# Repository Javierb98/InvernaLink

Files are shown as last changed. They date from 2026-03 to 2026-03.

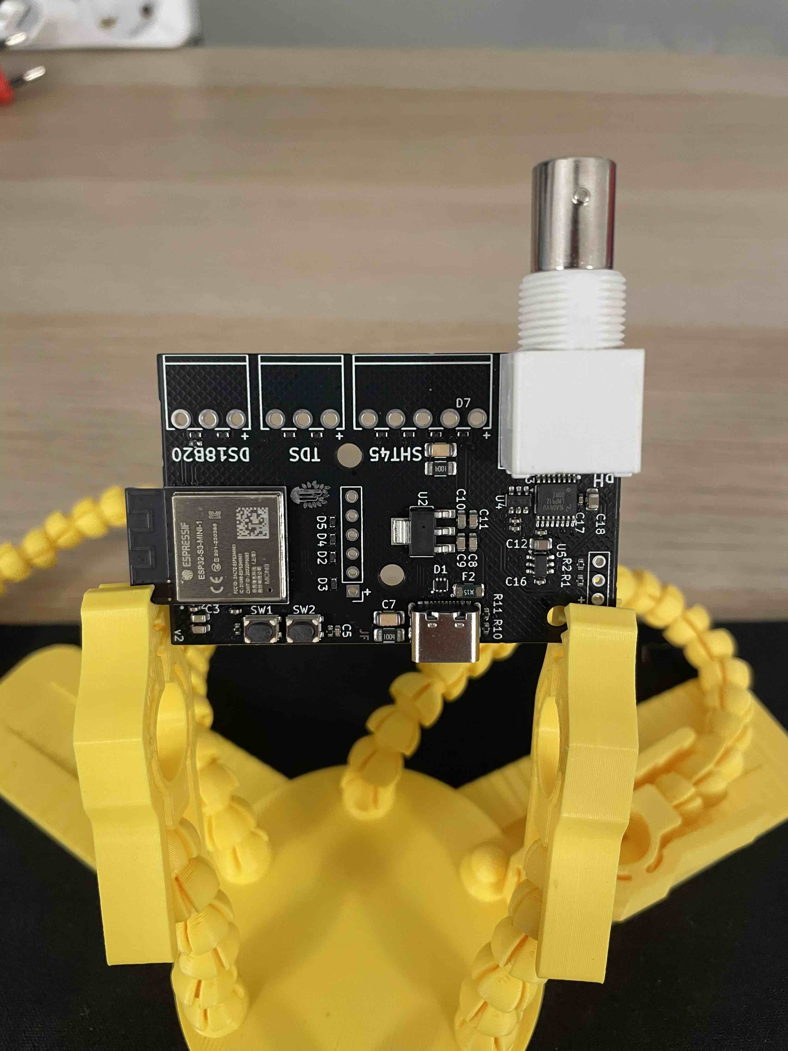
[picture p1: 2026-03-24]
Images/IMG_6064.jpg

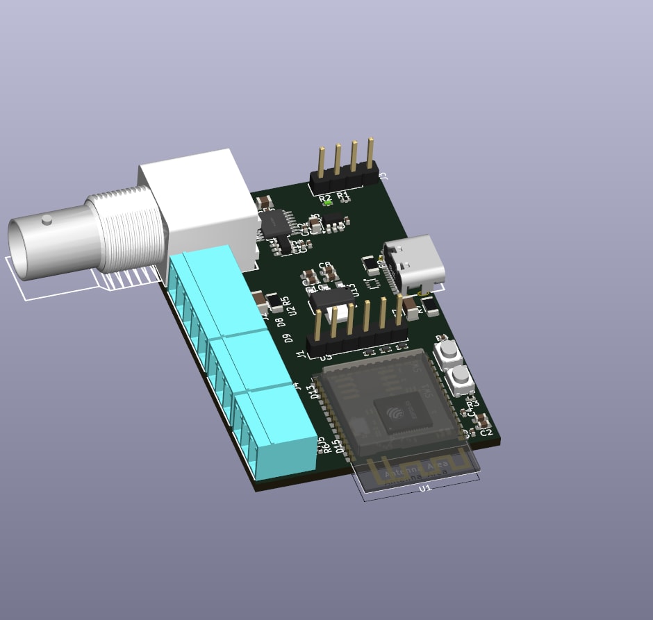
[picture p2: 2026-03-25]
Images/image.png.jpeg

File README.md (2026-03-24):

# Invernalink 🌱

**An open-source garden monitoring system powered by Home Assistant**

Invernalink is a modular, DIY-friendly system designed to help you monitor and automate your garden, greenhouse, or indoor growing environment. Built with flexibility and openness in mind, it integrates seamlessly with Home Assistant and is designed to be accessible for makers, growers, and developers alike.

---

## 🔗 Project Links

* 🌐 Project page: [https://evocultiva.org/project/invernalink-an-open-source-garden-monitoring-system-powered-by-home-assistant](https://evocultiva.org/project/invernalink-an-open-source-garden-monitoring-system-powered-by-home-assistant)
* 🛒 Support the project: (https://evocultiva.org/store/product/2)

---

## 📦 Repository Contents

This repository includes:

* **Gerber files** – Ready-to-manufacture PCB designs
* **STL files** – 3D-printable enclosures and components
* **YAML configurations** – Home Assistant integration and setup

Everything you need to build, modify, and extend Invernalink is here.

---

## 🚀 Features

* 🌡️ Environmental monitoring (temperature, humidity, CO2, Light etc.)
* 🔌 Home Assistant integration. you can 
* 🧩 Modular hardware design
* 🛠️ Fully customizable. The sensors are meant to be switched out and upgraded.

---

## 🧑‍🔧 Getting Started

1. Download or clone this repository
2. Manufacture the PCB using the provided Gerber files
3. 3D print the enclosure from the STL files
4. Assemble the hardware components
5. Import and adapt the YAML configuration into Home Assistant
6. Start monitoring your garden 🌿

> Detailed build instructions and documentation are available on the project page.

---

## 🤝 Contributing

Invernalink is an open-source project, and contributions are highly encouraged.

You can help by:

* Improving the hardware design
* Optimizing the PCB layout
* Enhancing the Home Assistant YAML configurations
* Adding new sensors or features
* Reporting bugs or suggesting improvements

Feel free to open issues, submit pull requests, or fork the project and experiment.

---

## 💡 Collaboration Invitation

This project is meant to grow with the community. Whether you're a developer, maker, or gardener, your ideas and improvements are welcome.

If you build your own version, modify the design, or extend the functionality, please share it! Let’s make Invernalink better together.

---

## ❤️ Support the Project

If you find Invernalink useful and want to support ongoing development, consider purchasing a kit or product from the store:

👉 [https://evocultiva.org/store/product/2](https://evocultiva.org/store/product/2)

Your support helps:

* Fund further development
* Improve documentation
* Expand features and compatibility
* Keep the project open and accessible

---

## 📜 License

This project is open-source. Please check the LICENSE file for details.

---

## 🌿 Final Notes

Invernalink is built on the idea that technology can empower sustainable growing. Whether you're managing a greenhouse or a small home garden, this system is here to help you understand and optimize your environment.

Happy growing! 🌱

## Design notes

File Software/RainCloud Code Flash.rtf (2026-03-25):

esphome:
name: sensor
friendly_name: InvernaLink

esp32:
board: esp32dev
framework:
type: arduino

# Define sensor pins as substitutions for easy modification

substitutions:
tds_pin: "2"
ds18b20_pin: "1"
tsl2591_int_pin: "21"

# Configure I2C for multiple sensors

i2c:
sda: GPIO15
scl: GPIO16
scan: true
id: bus_a

wifi:
ap:
ssid: “InvernaLink”
password: "12345678"

captive_portal:

api:

ota:
platform: esphome

logger:

web_server:
port: 80

# Sensors

sensor:
# TSL2591 Light Sensor

- platform: tsl2591
name: "Ambient Light"
id: light_sensor
address: 0x29
update_interval: 2s
interrupt_pin: GPIO${tsl2591_int_pin}
unit_of_measurement: "lux"

# SHT45 Temperature & Humidity Sensor

- platform: sht4x
temperature:
name: "Air Temperature"
humidity:
name: "Air Humidity"
address: 0x44
update_interval: 2s

# pH Sensor

- platform: ads1115
multiplexer: 'A0_GND'
gain: 4.096
name: "pH Level"
update_interval: 2s
unit_of_measurement: "pH"
accuracy_decimals: 1

# SCD41 CO2, Temperature & Humidity Sensor

- platform: scd4x
co2:
name: "CO2 Level"
temperature:
name: "SCD41 Temperature"
humidity:
name: "SCD41 Humidity"
address: 0x62
update_interval: 2s

# TDS Sensor

- platform: adc
pin: GPIO${tds_pin}
name: "TDS Level"
update_interval: 2s
unit_of_measurement: "ppm"
accuracy_decimals: 0

# DS18B20 Water Temperature Sensor

- platform: dallas
address: 0x28
pin: GPIO${ds18b20_pin}
name: "Water Temperature"
update_interval: 60s
unit_of_measurement: "°C"
accuracy_decimals: 1

# Dallas OneWire Bus for DS18B20

dallas:
- pin: GPIO${ds18b20_pin}

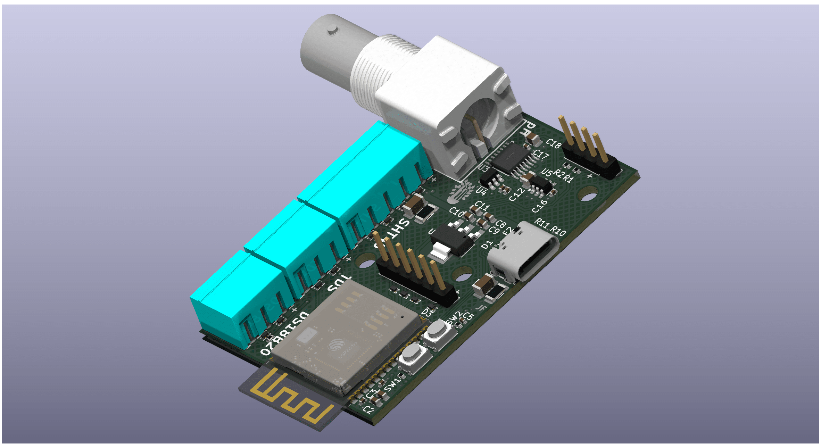
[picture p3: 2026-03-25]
Images/Side view.png

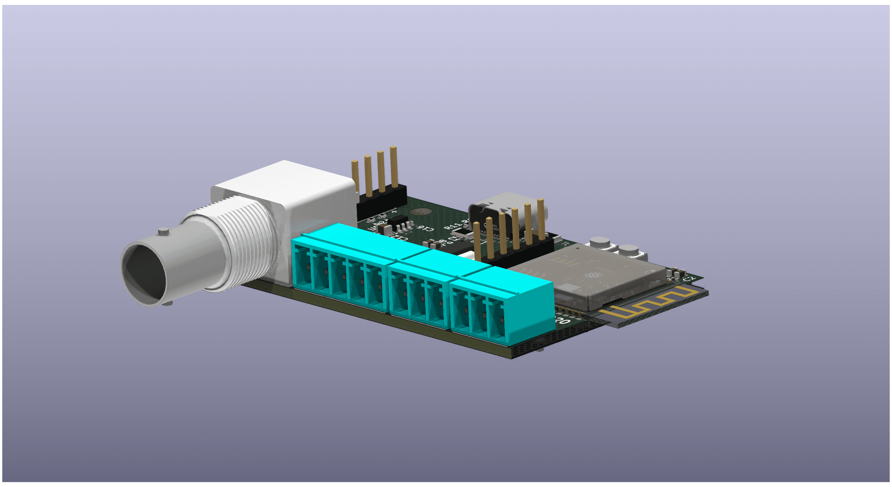
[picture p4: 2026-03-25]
Images/Front view.png

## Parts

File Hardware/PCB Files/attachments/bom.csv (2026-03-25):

Designator | Footprint | Quantity | Value | LCSC Part #
C1, C10, C11, C2, C8, C9 | 0603 | 6 | 10uF | C96446
C12, C18 | 0805 | 2 | 22uF | C45783
C13, C15, C16, C17, C3, C5 | 0402 | 6 | 100nF | C1525
C14, C4 | 0402 | 2 | 2.2uF | C12530
C6, C7 | 1206 | 2 | 4.7nF 2kV | C41017
D1 | SOT-666-6_L1.6-W1.2-P0.50-LS1.6-BL | 1 | USBLC6-2P6_C2827693 | C2827693
D12, D13, D14, D15, D2, D3, D4, D5, D6, D7, D8, D9 | DFN1006-2L-BI | 12 | JEN1006-3.3V-ULC | C2982301
F2 | 1206 | 1 | Polyfuse | C2153797
R1, R2 | 0402 | 2 | 2k | C4109
R10, R11 | 0402 | 2 | 5.1k | C25905
R3, R4 | 0402 | 2 | 10k | C25744
R5, R7 | 1206 | 2 | 1M | C17927
R6 | 0402 | 1 | 4.7k | C25900
RF1 | ANT-TH_KH-BNC75-3511 | 1 | KH-BNC75-3511 | C2837588
SW1, SW2 | SW-SMD_4P-L4.2-W3.2-P2.15-LS4.5 | 2 | GT-TC048D-H025-L1 | C843674
U13 | USB-C-SMD_GT-USB-7010I | 1 | GT-USB-7010I | C5362630
U2 | SOT-223-3_L6.5-W3.4-P2.30-LS7.0-BR-1 | 1 | HE2028A33FR | C5199431
U3 | TSSOP-16_L5.0-W4.4-P0.65-LS6.4-BL | 1 | LMP91200MTX/NOPB | C2678419
U4 | SOT-23-6 | 1 | MCP3421A0T-ECH | C29454
U5 | SOT-23-6 | 1 | REF35205QDBVR | C6966710
U6 | BULETM-SMD_ESP32-S3-MINI-1-N8 | 1 | ESP32-S3-MINI-1-N8 | C2913206

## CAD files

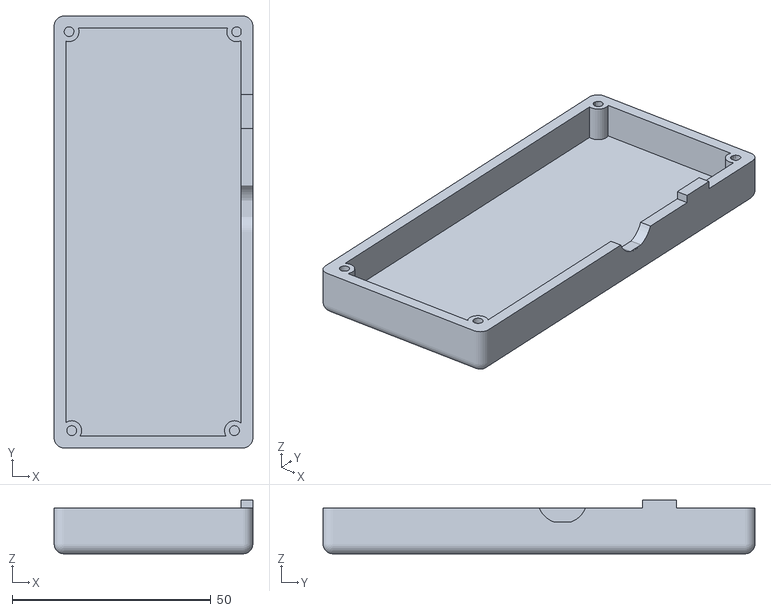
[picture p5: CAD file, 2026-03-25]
Hardware/STL case/RainCloud Box Upper.stl
50.0 x 108.7 x 13.5

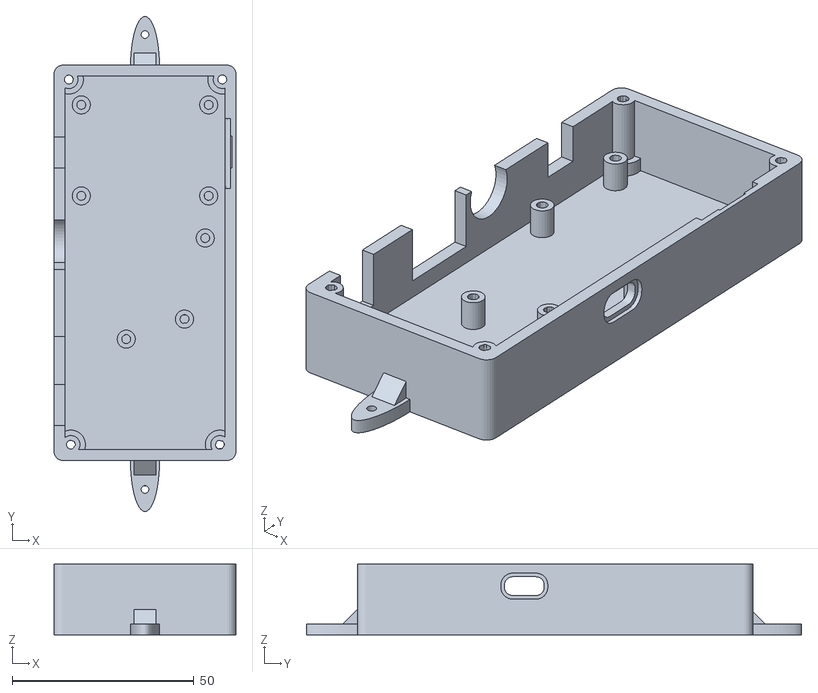
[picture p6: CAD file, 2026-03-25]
Hardware/STL case/RainCloud Box Lower.stl
50.0 x 136.0 x 19.5

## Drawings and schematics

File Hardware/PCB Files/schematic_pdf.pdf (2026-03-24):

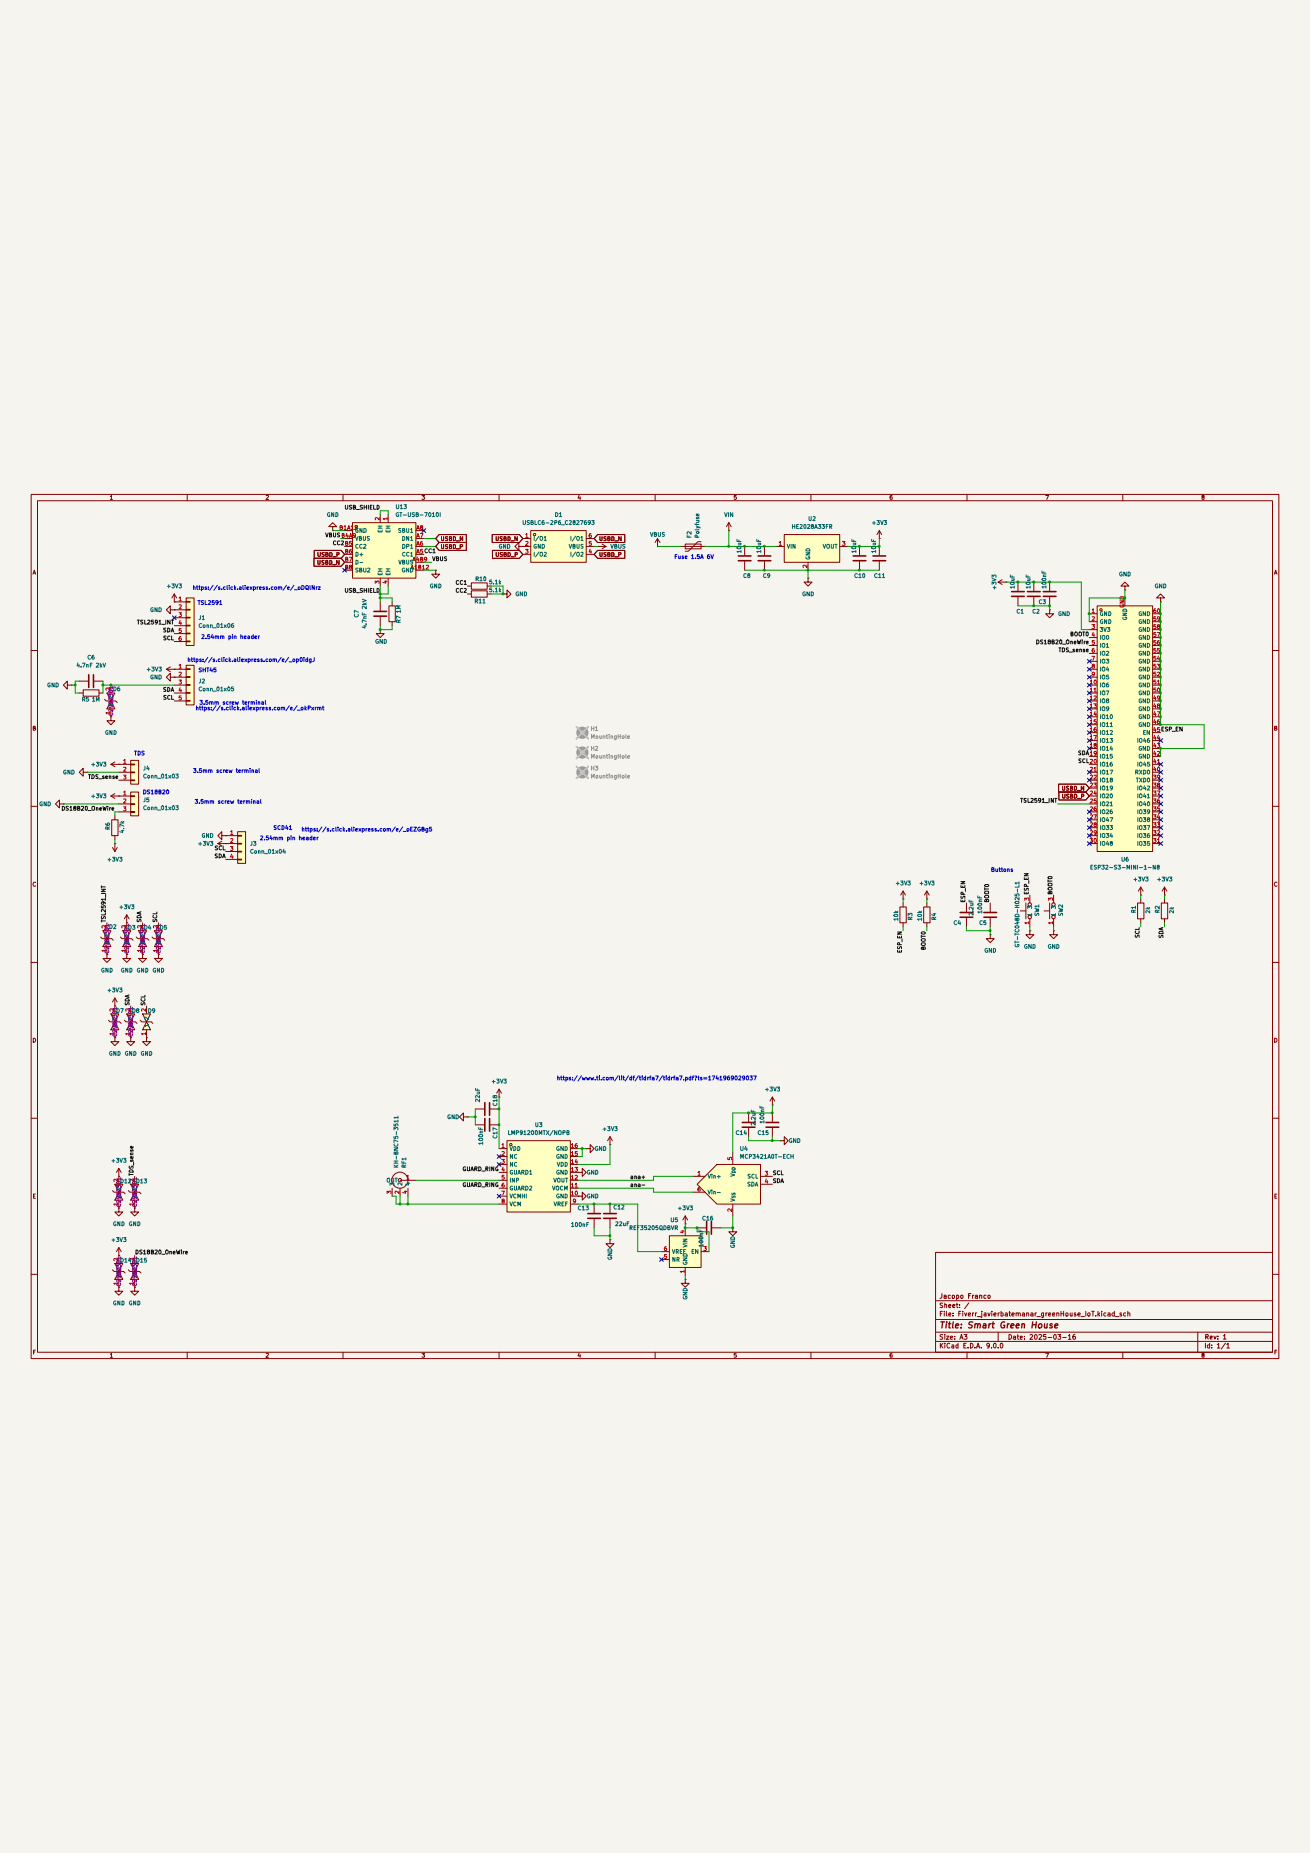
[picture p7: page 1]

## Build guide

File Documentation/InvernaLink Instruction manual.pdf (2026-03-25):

# OPERATORS MANUAL:

# INVERNALINK V1

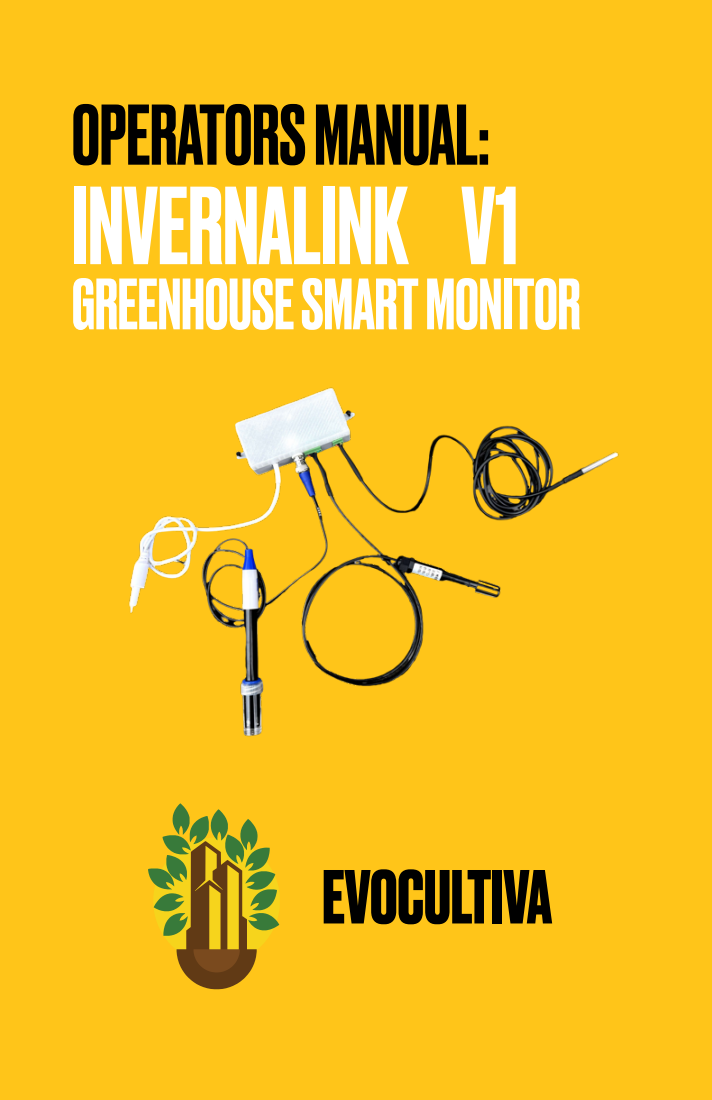
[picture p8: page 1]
EVOCULTIVA

GREENHOUSE SMART MONITOR

# TABLE OF CONTENTS

1. Components
2. Installation
3. Connecting to Wi-Fi
4. Integrating with Home Assistant
5. Connecting & Disconnecting Sensors
6. Safe Operation
7. Support & Warranty Information

© EvoCultiva
Javier Bateman Aramendia
www.Evocultiva.org

# COMPONENTS

A. USB-A to USB-C charging/data cable
B. TDS meter
C. TSL2591 (light sensor module
D. SCD40 (CO2 sensor module)
E. SHT40 (temp & humidity sensor)
F. DS18b20 (water temp module)
G. pH sensor
H. ESP32-S3-Mini

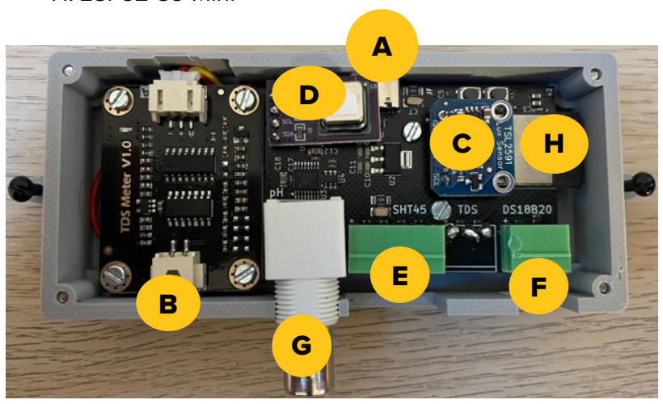
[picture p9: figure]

# INSTALLATION

To start, you need to set up an instance of Home Assistant. If you’ve purchased an InvernaLink Hub, refer to the installation manual for the InvernaLink Hub first. In the case that you’ve already got an instance of home assistant up, then we will install the InvernaLink.
1. decide where you want to install the InvernaLink, we recommend you install it close to your nutrient stock tank, in a position safe from being splashed by water. Do not cover the case in order to allow the light reading to function. Do not leave the case outside exposed to direct elements
2. When you’ve decided where you want it, make sure the case is oriented with the cables facing left and right. Use a marker and mark the two tab holes outside the case. Use these holes as the guide for whatever drilling you need to do, then simply attach the case via the pre drilled tabs
3. Once the case is setup, simply plug in the USB-C charge cable either to the InvernaLink Hub, or to an appropriate USB outlet to power it up You should be able to see a blue LED light up inside the case to indicate there is power.

# CONNECTING TO WI-FI AND HOME ASSISTANT

1. Wait 1–2 minutes after powering on.
2. Open Wi-Fi settings on your phone or computer.
3. Connect to the “InvernaLink” network.
4. In a browser (safari, crome, etc) go to 192.168.4.1
5. Input your home Wi-Fi name and password.
6. InvernaLink will then connect to your home network and shut down its temporary access point. This process might take 1-2 minutes, be patient.
7. Once the InvernaLink is connected to the wifi, go to your home assistant, and look for a new device. and add it to your dashboard as desired.
8. If for any reason the installation does not go smoothly, feel free to contact us on our website and we will help guide you through the installation process.

# CONNECTING & DISCONNECTING SENSORS

To ensure safe and reliable operation when connecting or disconnecting sensors, follow these guidelines:
Sensor Lifespan
The light, CO2, air temp/humidity, and water temp sensors should last for years to come if well taken care of.
The pH sensor is shortest lived, though it self calibrates the life of the sensor assuming it is constantly submerged will be between 6-8 months, after that its accuracy will diminish
the EC sensor should last a few years if you make sure to keep it in good condition (don’t allow bacteria and mold to build up on it in order to increase lifespan). Power Safety
Always disconnect power before connecting or removing any sensors to prevent electrical shorts or damage to internal components.
Avoid touching exposed contacts when the device is powered.
Approved Cables and Ports
Use only the supplied USB-C cable and ensure all connectors are compatible with the InvernaLink system.

For extensions or replacements, use cables and adapters rated for data and power transmission. Moisture and Corrosion Check
Inspect all sensor connectors and ports for moisture, rust, or corrosion before making any connections. If any moisture is present, dry thoroughly and clean with isopropyl alcohol if needed before plugging in. Sensor Handling
Handle sensors by the plastic housing or designated grip areas. Avoid pulling on wires.
Do not bend or stress sensor cables unnecessarily; use strain reliefs if installing in permanent locations. Connection Order
Connect sensors only after the InvernaLink unit is securely mounted and powered off.
Plug in one sensor at a time and ensure a snug, secure fit. Loose connections may result in faulty readings. Disconnecting Sensors
To disconnect, gently pull the connector, not the cable, to avoid damaging the wire or port.
Do not twist or force connectors—if resistance is felt, double-check alignment and try again.
After Reconnecting
Once reconnected and powered on, verify that all sensors are being detected correctly in your Home Assistant dashboard or monitoring software.

# SAFE OPERATION

To ensure the safe and effective operation of your InvernaLink device, please adhere strictly to the following guidelines:

Environmental Exposure
The InvernaLink is not rated for outdoor or unprotected use. Do not expose the unit to direct exposed intense sunlight, as intense UV light and heat can accelerate aging.
Avoid rain, humidity, or other moisture sources.
Keep the device away from excessive heat or freezing temperatures.
Exposure to these conditions may cause malfunction or permanent damage. Damage due to environmental misuse is not covered under warranty.

Installation Location
Install the InvernaLink in a dry, well-ventilated space.
Avoid areas near pressurized water, or other fluid hazards.
Mount the unit securely using the provided hardware.
Improper installation can lead to device failure, electrical shock, or injury.

Handling and Supervision
Keep the device out of reach of children and pets.
Do not permit unauthorized persons to operate, handle, or modify the device.
Always supervise use in shared or public settings.

Device Integrity
Inspect the enclosure and cables regularly for:

Physical damage, cracks, signs of water ingress, loose or frayed wires

If damage is suspected, discontinue use immediately and contact EvoCultiva support.

Electrical Safety
Use only the approved USB-C power cable and compatible power supply.
Do not operate the unit with wet hands or in damp environments. Always disconnect power before moving, cleaning, or modifying the device.

Tampering and Modifications
The InvernaLink contains sensitive electronic components.
Do not open the case or make internal modifications unless you are experienced with electronics.
Unauthorized tampering voids the warranty and may cause malfunction, fire risk, or injury.

Liability Disclaimer
EvoCultiva is not liable for any damages, injuries, or losses arising from:
- Misuse
- Improper installation
- Unauthorized modifications
- Failure to follow these safety guidelines
It is your responsibility to ensure the InvernaLink is used in compliance with local electrical and safety regulations.

# SUPPORT AND WARRANTY INFORMATION

Customer Support

Thank you for choosing EvoCultiva. We’re committed to providing reliable, long-term support for your InvernaLink system. If you encounter any issues or have questions about installation, setup, or operation, our support team is ready to help.

Contact Us

- Phone: (+34) 628-358-371
- Website: www.evocultiva.org/contact

Support hours: Monday to Friday, 9:00 AM – 5:00 PM (Local Time)

Limited Warranty

InvernaLink is backed by a 1-year limited warranty from the date of purchase. This warranty covers defects in materials or workmanship under normal use and conditions.

Covered under warranty:

- Manufacturing or assembly defects
- Faulty internal components or hardware
- Failures resulting from normal use within operating guidelines

Not covered under warranty:

- Damage from misuse, abuse, or improper installation
- Water damage (unless specified as waterproof)
- Modifications or repairs by unauthorized personnel
- Accidental damage or natural disasters

How to Make a Warranty Claim

To initiate a warranty claim:

1. Contact EvoCultiva Support with a detailed description of the issue.
2. Include proof of purchase (receipt or invoice) and product serial number.
3. Our support team will provide instructions for repair, replacement, or return, if applicable.

Shipping Policy: Return shipping may be the responsibility of the customer unless otherwise stated by EvoCultiva.
